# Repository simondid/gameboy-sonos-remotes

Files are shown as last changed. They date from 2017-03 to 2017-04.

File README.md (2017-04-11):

#gameboy zero w sonos controler

## Interface
Logo Title Text 1

## setup

### running the jar
```sh
to run the jar
clientid = spotify client id
clientsecretkey = spotify client secret key
userid = username
fullscreen mode = true ore false
wifiManger (turns wifi on and off in sleep mode) = true ore false

java -jar gameboy-sonos-remotes clientid clientsecretKey userid wifiManger
```
### setup off 3.5 inc tft screen

```sh
screen setup

cd /boot
sudo nano config.txt

see piSettingsFiles for config.txt changes
link
https://github.com/simondid/gameboy-sonos-remotes/blob/master/readMeImages/config.txt
```

### runnable .sh file no terminal window output

```sh
#!/bin/bash

sudo nohup java -jar "path to youre jar "/gameboy-sonos-remotes.jar sonosip clientid clientsecretKey userid fullscreenMode

```
run in therminal on the script file
```sh
sudo chmod +x "youre .sh filename"
```
### runnable .sh file with terminal window

```sh
#!/bin/bash

sudo java -jar "path to youre jar "/gameboy-sonos-remotes.jar sonosip clientid clientsecretKey userid fullscreenMode

```
run in therminal on the script file
```sh
sudo chmod +x "youre .sh filename"
```
### auto .sh file on boot (dos the job but bad fix)
auto start lxterminal and the lxterminal auto starts a .sh script

```sh
sudo nano .config/lxsession/LXDE-pi/autostart
```

add to autostart file

```sh
@lxterminal
```
fixing lxterminal window size
```sh
@lxterminal --geometry=39x9
```

then edit
```sh
sudo nano .bashrc
```
add to the end off the file no < >

```sh
bash < my .sh file name if located in /home/pi/ >
```

### setting raspbian ssh password

```sh
passwd
```
follow instructions

### ACT and PWR LED controle
commands work but seems unstable multiple class seems to be the bedst fix atm

```
echo 0 | sudo tee /sys/class/leds/led1/brightness

echo 1 | sudo tee /sys/class/leds/led0/brightness
```

# hardware
pi zero w
adafruit powerboost 1000c
lipo fuel gauge max 17043
2000mha lipo battery ( power test screen off for the intire test gives 7 houres and 1 minutes off battery life )

## electronics wiring

### screen on / off controler
new cercuit

using a fqp47p06

http://www.mouser.com/ds/2/149/FQP47P06-1009447.pdf
http://i63.tinypic.com/21e9aw2.jpg

screen on / off controler

```
old screen controler circuit

http://i63.tinypic.com/11jc6mq.png
http://electronics.stackexchange.com/questions/233205/npn-transistor-to-run-12v-0-5a-from-3-3v-4ma

gpio 1 aka pin 12 on the raspberry pi model b

![screen on / off controler](http://i63.tinypic.com/11jc6mq.png "screen on / off controler")
```
### battery management circuit based on the max17043 lipo fuel gauge
http://i65.tinypic.com/xdf0wi.png
https://github.com/simondid/MAX17043

the battery management code is gonna be based on my max17043 class

https://github.com/simondid/MAX17043

battery circuit

# optional

## power saving

### cpu throttling / dynamic cpu speed

powersvaings uncorfirmed

in /boot/config.txt

force_turbo=0
arm_freq_min=200

^makes the cpu switch between default cpy speed and the value off arm_freq_min

http://with-raspberrypi.blogspot.dk/2014/03/cpu-frequency.html

### wifi on and off

power svaings messured with low accuracy but around 3 ma

this is included in the program and is enabled bay default

see post bay "yavuzaksan"

wifi off
sudo iwconfig wlan0 txpower off

wifi on
sudo iwconfig wlan0 txpower 1

http://raspberrypi.stackexchange.com/questions/43720/disable-wifi-wlan0-on-pi-3

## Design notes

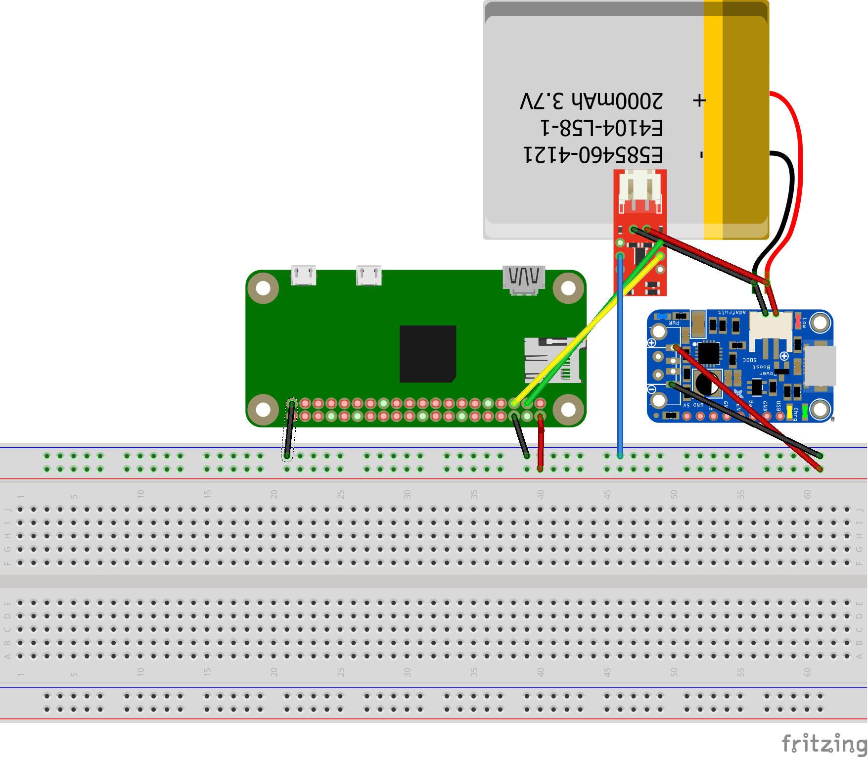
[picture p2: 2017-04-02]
readMeImages/sketches/battery sketch_bb.png

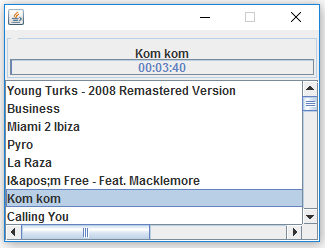
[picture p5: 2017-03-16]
readMeImages/interface.PNG

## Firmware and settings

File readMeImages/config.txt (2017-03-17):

# For more options and information see
# http://www.raspberrypi.org/documentation/configuration/config-txt.md
# Some settings may impact device functionality. See link above for details

# uncomment if you get no picture on HDMI for a default "safe" mode
#hdmi_safe=1

# uncomment this if your display has a black border of unused pixels visible
# and your display can output without overscan
disable_overscan=0

# uncomment the following to adjust overscan. Use positive numbers if console
# goes off screen, and negative if there is too much border
#overscan_left=32
overscan_right=-25
#overscan_top=16
overscan_bottom=-25

# uncomment to force a console size. By default it will be display's size minus
# overscan.
framebuffer_width=320
framebuffer_height=240

# uncomment if hdmi display is not detected and composite is being output
#hdmi_force_hotplug=1

# uncomment to force a specific HDMI mode (this will force VGA)
#hdmi_group=2
#hdmi_mode=82

# uncomment to force a HDMI mode rather than DVI. This can make audio work in
# DMT (computer monitor) modes
#hdmi_drive=2

# uncomment to increase signal to HDMI, if you have interference, blanking, or
# no display
#config_hdmi_boost=4

# uncomment for composite PAL
sdtv_mode=2
sdtv_aspect=1

#uncomment to overclock the arm. 700 MHz is the default.
arm_freq=1000

# Uncomment some or all of these to enable the optional hardware interfaces
#dtparam=i2c_arm=on
#dtparam=i2s=on
#dtparam=spi=on

# Uncomment this to enable the lirc-rpi module
#dtoverlay=lirc-rpi

# Additional overlays and parameters are documented /boot/overlays/README

# Enable audio (loads snd_bcm2835)
dtparam=audio=on
core_freq=500
sdram_freq=500
over_voltage=2

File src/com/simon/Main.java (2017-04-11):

package com.simon;


import com.pi4j.io.gpio.*;
import com.pi4j.io.gpio.event.GpioPinDigitalStateChangeEvent;
import com.pi4j.io.gpio.event.GpioPinListenerDigital;
import com.pi4j.io.gpio.trigger.GpioCallbackTrigger;
import com.pi4j.io.gpio.trigger.GpioSetStateTrigger;
import com.pi4j.io.gpio.trigger.GpioTrigger;
import com.pi4j.io.i2c.I2CBus;
import com.pi4j.io.i2c.I2CFactory;
import com.pi4j.system.SystemInfo;
import com.simon.max1704x_lipo_gauge.max17043;
import com.simon.sonos.*;
import com.simon.spotify.*;

import com.simon.ui2.InfoPanel;
import com.simon.ui2.frame;

import javax.sound.midi.Soundbank;
import javax.swing.*;
import java.awt.*;
import java.awt.event.ActionEvent;
import java.awt.event.ActionListener;
import java.awt.event.KeyEvent;
import java.io.FileNotFoundException;
import java.io.FileOutputStream;
import java.io.IOException;
import java.io.PrintStream;
import java.text.ParseException;
import java.text.SimpleDateFormat;
import java.util.ArrayList;
import java.util.Calendar;
import java.util.concurrent.Callable;

public class Main {
    public static String ipAddress = "";
    static String clientId = "";
    static String clientSecret = "";
    static String userid = "";

    public static ArrayList<item> activeList;
    public static ArrayList<item> queuePreBuf;
    public static ArrayList<item> SpotifyPreBuf;
    public static String[] firstList = {"radio", "queue", "Spotify", "tv"};
    public static ArrayList<deviceDescription> deviceList;
    public static int firstListFlag = -2;
    public static Sonos sonos = null;
    public static frame gui;
    public static ArrayList<item> radioStationList;
    static Spotify spotify;
    public static GpioPinDigitalInput ButtonLeft, ButtonRight, ButtonUp, ButtonDown, ButtonA, ButtonB, ButtonSelect, ButtonStart;
    public static GpioPinDigitalOutput ScreenPin;
    public static GpioController gpio;
    public static boolean fullscreen = false;
    public static int debounceTime = 500;
    public static Timer screenTimer;
    public static boolean Pi4jActive = false;
    public static final int defaultBatteryShutdownSOC = 3;
    public static boolean wifiState = true;
    public static ArrayList<Timer> timers;
    public static boolean wifiManager=false;
    public static Thread DeviceLisenter;
    public static void main(String[] args) throws InterruptedException {
        timers = new ArrayList<>();
//            Shutdown shutdown = new Shutdown();
        try {
            Runtime.getRuntime().addShutdownHook(new ShutdownThread());
            System.out.println("[Main thread] Shutdown hook added");
        } catch (Throwable t) {
//             we get here when the program is run with java
//             version 1.2.2 or older
            System.out.println("[Main thread] Could not add Shutdown hook");
        }
        ui();
        Thread.sleep(5000);
        setFirstListGui();
        gui.Infopanel.LoadingIconOFF();

        wifiOn();


        System.getProperties().list(System.out);
//
        try {
            new systeminfoPrint();
        } catch (IOException e) {
            e.printStackTrace();
        } catch (ParseException e) {
            e.printStackTrace();
        }

//        ipAddress = args[0];
        clientId = args[0];
        clientSecret = args[1];
        userid = args[2];
        if(args[3].contains("true")||args[3].contains("1")){
            fullscreen=true;
        }
        if(args[4].contains("true")||args[4].contains("1")){
            wifiManager=true;
        }



        spotify = new Spotify(clientId, clientSecret, userid);

        activeList = new ArrayList<>();
        gpio = null;



        Timer timer = new Timer(10000, new ActionListener() {
            @Override
            public void actionPerformed(ActionEvent e) {
                Calendar cal = Calendar.getInstance();
                SimpleDateFormat sdf = new SimpleDateFormat("HH:mm:ss");
                System.out.println("time : " + sdf.format(cal.getTime()));

            }
        });
        timers.add(timer);
        timer.start();
//        Timer wifi = new Timer(90000, new ActionListener() {
//            @Override
//            public void actionPerformed(ActionEvent e) {
//                if (wifiState) {
//                    wifiOn();
//                    wifiState = false;
//                } else {
//                    wifiOff();
//                    wifiState = true;
//                }
//
//            }
//        });
//        wifi.start();


        try {
            updateDevicelink();

//
        } catch (Exception e) {
            e.printStackTrace();
        }
        if(Pi4jActive) {
            try {
                new VolumeControle();
            } catch (IOException e) {
                e.printStackTrace();
            } catch (I2CFactory.UnsupportedBusNumberException e) {
                e.printStackTrace();
            }
        }

            screenTimer = new Timer(60000, new ActionListener() {
                @Override
                public void actionPerformed(ActionEvent e) {
                    if (Pi4jActive){
                        ScreenPin.high();
                    try {
                        Thread.sleep(10000);
                    } catch (InterruptedException e1) {
                        e1.printStackTrace();
                    }
                   wifiOff();
                }
            }
            });
            timers.add(screenTimer);
            screenTimer.start();
            Thread.sleep(5000);
            if (!System.getProperty("os.name").contains("Windows")) {
                Pi4jActive = true;
            }
            if (Pi4jActive) {
                pi4jSetup();
                LowPowerCalls.turnOffOnbordLeds();


            }


//        while(true){
//            Thread.sleep(10000);
//        }

    }

    public static void updateDevicelink() {
        DeviceLisenter = new Thread(new Runnable() {
            @Override
            public void run() {
                gui.Infopanel.LoadingIconON();
                Upnp_Discover discover = new Upnp_Discover();
                discover.start();
                while(discover.isAlive()){
                    ArrayList<deviceDescription> list = discover.getDevices();
                    for(int i =0;i<list.size();i++){
                        System.out.println("returned stuff : "+list.get(i).getIp());
                        setNewGuiListDevices(list);
                    }
                    try {
                        Thread.sleep(3000);
                    } catch (InterruptedException e) {
                        e.printStackTrace();
                    }
                }
                ArrayList<deviceDescription> list = discover.getDevices();
                for(int i =0;i<list.size();i++){
                    System.out.println("returned stuff : "+list.get(i).getIp());
                    setNewGuiListDevices(list);
                }
                gui.Infopanel.LoadingIconOFF();
            }

        });
        DeviceLisenter.start();
    }


    public static void wifiOff(){

        if(Pi4jActive && wifiManager) {
            wifiState = false;
            Thread t = new Thread(new Runnable() {
                @Override
                public void run() {
                    String[] args = new String[]{"/bin/bash", "-c", "sudo iwconfig wlan0 txpower off"};
                    try {
                        Process proc = new ProcessBuilder(args).start();
                    } catch (IOException e) {
                        e.printStackTrace();
                    }
                    System.out.println("turning wifi off");
                }
            });
            t.start();
        }
    }
    public static void wifiOn() {

        if(Pi4jActive && wifiManager) {
            wifiState = true;
            Thread t = new Thread(new Runnable() {
                @Override
                public void run() {
                    String[] args = new String[]{"/bin/bash", "-c", "sudo iwconfig wlan0 txpower 1"};
                    try {
                        Process proc = new ProcessBuilder(args).start();
                    } catch (IOException e) {
                        e.printStackTrace();
                    }
                    System.out.println("turning wifi on");
                }
            });
            t.start();
        }
    }


    private static void pi4jSetup() {

//        try {
//            Robot  r = new Robot();
//        } catch (AWTException e) {
//            e.printStackTrace();
//        }
        final GpioController instance = GpioFactory.getInstance();

        gpio = instance;

        try {
            max17043 max = new max17043(I2CFactory.getInstance(I2CBus.BUS_1));
            max.clearAlertInterrupt();
            max.setAlertThreshold(defaultBatteryShutdownSOC);

        } catch (IOException e) {
            e.printStackTrace();
        } catch (I2CFactory.UnsupportedBusNumberException e) {
            e.printStackTrace();
        } catch (InterruptedException e) {
            e.printStackTrace();
        }


        pi4jButtonLeftSetup(); // gpio 02
        pi4jButtonRightSetup(); // gpio 00
        pi4jButtonUpSetup(); // gpio 10
        pi4jButtonDownSetup(); // gpio 04
        pi4jButtonASetup(); //gpio 06
        pi4jButtonBSetup(); // gpio 5
        pi4jButtonStartSetup(); // gpio 11
        pi4jButtonSelectSetup(); // gpio 07
        pi4jScreenControler(); // gpio 8 and 9



    }

    public static void screenToogle(){
      ScreenPin.toggle();
        System.out.println("scrren is : " + ScreenPin.getState());
    }
    private static void pi4jScreenControler() {
       ScreenPin = gpio.provisionDigitalOutputPin(RaspiPin.GPIO_01);
       ScreenPin.setShutdownOptions(true,PinState.LOW);
    }

    public static void pi4jButtonSelectSetup(){
        ButtonSelect = gpio.provisionDigitalInputPin(RaspiPin.GPIO_07, PinPullResistance.PULL_DOWN);
        ButtonSelect.setShutdownOptions(true);
        ButtonSelect.setDebounce(debounceTime);
        ButtonSelect.addListener(new GpioPinListenerDigital() {

            @Override
            public void handleGpioPinDigitalStateChangeEvent(GpioPinDigitalStateChangeEvent event) {
                // display pin state on console
                System.out.println(" --> GPIO PIN STATE CHANGE: " + event.getPin() + " = " + event.getState());
                try {
                    Robot  r = new Robot();
                    if(event.getState().isHigh()) {
                        r.keyPress(KeyEvent.VK_D);
                    }else {
                        r.keyRelease(KeyEvent.VK_D);
                    }
                } catch (AWTException e) {
                    e.printStackTrace();
                }
//
            }

        });
    }
    public static void pi4jButtonStartSetup(){
        ButtonStart = gpio.provisionDigitalInputPin(RaspiPin.GPIO_11, PinPullResistance.PULL_DOWN);
        ButtonStart.setShutdownOptions(true);
        ButtonStart.setDebounce(debounceTime);
        ButtonStart.addListener(new GpioPinListenerDigital() {

            @Override
            public void handleGpioPinDigitalStateChangeEvent(GpioPinDigitalStateChangeEvent event) {
                // display pin state on console
                System.out.println(" --> GPIO PIN STATE CHANGE: " + event.getPin() + " = " + event.getState());
                try {
                    Robot  r = new Robot();
                    if(event.getState().isHigh()) {
                        r.keyPress(KeyEvent.VK_S);
                    }else {
                        r.keyRelease(KeyEvent.VK_S);
                    }
                } catch (AWTException e) {
                    e.printStackTrace();
                }

            }

        });
    }
    public static void pi4jButtonBSetup(){
        ButtonB = gpio.provisionDigitalInputPin(RaspiPin.GPIO_05, PinPullResistance.PULL_DOWN);
        ButtonB.setShutdownOptions(true);
        ButtonB.setDebounce(debounceTime);
        ButtonB.addListener(new GpioPinListenerDigital() {

            @Override
            public void handleGpioPinDigitalStateChangeEvent(GpioPinDigitalStateChangeEvent event) {
                // display pin state on console
                System.out.println(" --> GPIO PIN STATE CHANGE: " + event.getPin() + " = " + event.getState());
                try {
                    Robot  r = new Robot();
                    if(event.getState().isHigh()) {
                        r.keyPress(KeyEvent.VK_LEFT);
                    }else {
                        r.keyRelease(KeyEvent.VK_LEFT);
                    }
                } catch (AWTException e) {
                    e.printStackTrace();
                }

            }

        });
    }
    public static void pi4jButtonASetup(){
        ButtonA = gpio.provisionDigitalInputPin(RaspiPin.GPIO_06, PinPullResistance.PULL_DOWN);
        ButtonA.setShutdownOptions(true);
        ButtonA.setDebounce(debounceTime);
        ButtonA.addListener(new GpioPinListenerDigital() {

            @Override
            public void handleGpioPinDigitalStateChangeEvent(GpioPinDigitalStateChangeEvent event) {
                // display pin state on console
                System.out.println(" --> GPIO PIN STATE CHANGE: " + event.getPin() + " = " + event.getState());
                try {
                    Robot  r = new Robot();
                    if(event.getState().isHigh()) {
                        r.keyPress(KeyEvent.VK_ENTER);
                    }else {
                        r.keyRelease(KeyEvent.VK_ENTER);
                    }
                } catch (AWTException e) {
                    e.printStackTrace();
                }
//
            }

        });
    }
    public static void pi4jButtonDownSetup(){
        ButtonDown = gpio.provisionDigitalInputPin(RaspiPin.GPIO_04, PinPullResistance.PULL_DOWN);
        ButtonDown.setShutdownOptions(true);
        ButtonDown.setDebounce(debounceTime);
        ButtonDown.addListener(new GpioPinListenerDigital() {

            @Override
            public void handleGpioPinDigitalStateChangeEvent(GpioPinDigitalStateChangeEvent event) {
                // display pin state on console
                System.out.println(" --> GPIO PIN STATE CHANGE: " + event.getPin() + " = " + event.getState());
                try {
                    Robot  r = new Robot();
                    if(event.getState().isHigh()) {
                        r.keyPress(KeyEvent.VK_DOWN);
                    }else {
                        r.keyRelease(KeyEvent.VK_DOWN);
                    }
                } catch (AWTException e) {
                    e.printStackTrace();
                }

            }

        });
    }
    public static void pi4jButtonUpSetup(){
//        ButtonUp = gpio.provisionDigitalInputPin(RaspiPin.GPIO_08, PinPullResistance.PULL_DOWN);
        ButtonUp = gpio.provisionDigitalInputPin(RaspiPin.GPIO_10);
        ButtonUp.setShutdownOptions(true);
        ButtonUp.setDebounce(debounceTime);
        ButtonUp.addListener(new GpioPinListenerDigital() {

            @Override
            public void handleGpioPinDigitalStateChangeEvent(GpioPinDigitalStateChangeEvent event) {
                // display pin state on console
                System.out.println(" --> GPIO PIN STATE CHANGE: " + event.getPin() + " = " + event.getState());
                try {
                    Robot  r = new Robot();
                    if(event.getState().isHigh()) {
                        r.keyPress(KeyEvent.VK_UP);
                    }else {
                        r.keyRelease(KeyEvent.VK_UP);
                    }
                } catch (AWTException e) {
                    e.printStackTrace();
                }

            }

        });
    }
    public static void pi4jButtonRightSetup(){
        ButtonRight = gpio.provisionDigitalInputPin(RaspiPin.GPIO_00, PinPullResistance.PULL_DOWN);
        ButtonRight.setShutdownOptions(true);
        ButtonRight.setDebounce(debounceTime);
        ButtonRight.addListener(new GpioPinListenerDigital() {

            @Override
            public void handleGpioPinDigitalStateChangeEvent(GpioPinDigitalStateChangeEvent event) {
                // display pin state on console
                System.out.println(" --> GPIO PIN STATE CHANGE: " + event.getPin() + " = " + event.getState());
                try {
                    Robot  r = new Robot();
                    if(event.getState().isHigh()) {
                        r.keyPress(KeyEvent.VK_RIGHT);
                    }else {
                        r.keyRelease(KeyEvent.VK_RIGHT);
                    }
                } catch (AWTException e) {
                    e.printStackTrace();
                }

            }

        });
    }
    public static void pi4jButtonLeftSetup(){
        ButtonLeft = gpio.provisionDigitalInputPin(RaspiPin.GPIO_02, PinPullResistance.PULL_DOWN);
        ButtonLeft.setShutdownOptions(true);
        ButtonLeft.setDebounce(debounceTime);


        ButtonLeft.addListener((GpioPinListenerDigital) event -> {
//                 display pin state on console
            System.out.println(" --> GPIO PIN STATE CHANGE: " + event.getPin() + " = " + event.getState());
            try {
                Robot  r = new Robot();
                if(event.getState().isHigh()) {
                    r.keyPress(KeyEvent.VK_LEFT);
                }else {
                    r.keyRelease(KeyEvent.VK_LEFT);
                }
            } catch (AWTException e) {
                e.printStackTrace();
            }

        });
    }

    private static void ui() {

        // new FullScreenJFrame();

        // gui = new gui2(false);

         gui = new frame(fullscreen);
    }

    public static void getSpotifyPlayLists(){
        setNewGuiList(SpotifyPreBuf);
        Thread t = new Thread(){
            @Override
            public synchronized void start() {
                super.start();
                gui.Infopanel.LoadingIconON();
                setNewGuiList(Spotify.GetPublicPlayLists());
                gui.Infopanel.LoadingIconOFF();
            }
        };
        t.start();
    }
    public static void getQueue() {
        setNewGuiList(queuePreBuf);

        Sonos s = sonos;

            Thread t = new Thread() {
                @Override
                public void run() {
                    super.run();
                    gui.Infopanel.LoadingIconON();
                    try {
                        activeList = s.BrowseQueue(0, 0, 0);
                    } catch (IOException e) {
                        e.printStackTrace();
                    }
                    setNewGuiList(activeList);
                    queuePreBuf = activeList;
                    firstListFlag = 1;
                    gui.Infopanel.LoadingIconOFF();
                }
        };
            t.start();

    }
    public static void getMusicFolders(){
        browse data = null;
        try {
            data = sonos.BrowseMusicFolders();
         setNewGuiList(sonos.ItemAnalyser(data.container.get(0).containerId));
    } catch (IOException e) {
        e.printStackTrace();
        }
    }

    public static void setNewGuiList(ArrayList<item> itemList) {
        Thread t = new Thread(){
            @Override
            public void run() {
                if(itemList!=null) {
                    String[] newlist = new String[itemList.size()];
                    for (int i = 0; i < itemList.size(); i++) {
                        newlist[i] = itemList.get(i).title;
                    }
                    activeList = itemList;
                    frame.newList(newlist);
                }

            }
        };

        t.start();
    }
    public static void setNewGuiListDevices(ArrayList<deviceDescription> itemList) {
        Thread t = new Thread(){
            @Override
            public void run() {
                if(itemList!=null) {
                    String[] newlist = new String[itemList.size()];
                    for (int i = 0; i < itemList.size(); i++) {
                        newlist[i] = itemList.get(i).ip;
                    }
                    deviceList = itemList;
                    frame.newList(newlist);
                }

            }
        };

        t.start();
    }

    public static void setFirstListGui() {
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

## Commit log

2017-03-16 fixing full screen ui for multiple screen sizes
    threading for playtime and info panel update
    [InfoPanel.java, Main.java]
2017-03-16 traying to fix button debunce
    [Main.java]
2017-03-16 bug fix when using radios stilled bugged on selection
    [InfoPanel.java, Main.java]
2017-03-17 traying to make screenOn and screenOFF function no luck
    [config.txt]
2017-03-21 added volume controle based on ads1115 with i2c connection
2017-03-24 Volume controle disabled do to unstabillity
    pi4j gpio acces disabled do to lag off implementation / support for raspberry pi zero w
2017-03-27 on off screen controler circuit added to readme
2017-03-28 process handling wile in low power mode
2017-03-30 More power saving stuff ( PWR and ACT led on / off functions added)
2017-04-02 added battery management circuit + max17043 controler class
    [battery sketch.fzz]
2017-04-04 more battery managemente
2017-04-08 wifi manager sleep mode / power management
2017-04-09 updatet screen controle circuit
2017-04-09 added folder contaning code for the arduino usb simulator
2017-04-11 changes made to add dynamic device selection
